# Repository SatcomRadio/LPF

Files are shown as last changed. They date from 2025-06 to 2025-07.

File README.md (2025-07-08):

# Low pass filter board

This repo consists of a board for making a low pass filter (LPF). 

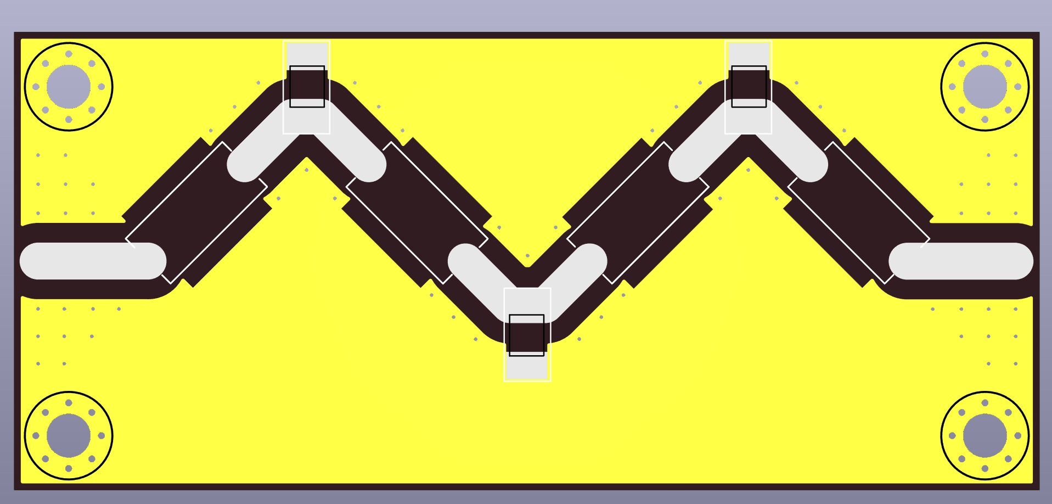
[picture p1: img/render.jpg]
render


You can use it with your own coils and RF capacitors for your desired frequency.

You can use a metal box like [this one](https://www.aliexpress.com/item/1005001849603652.html) of size 92x38x31mm to store it.

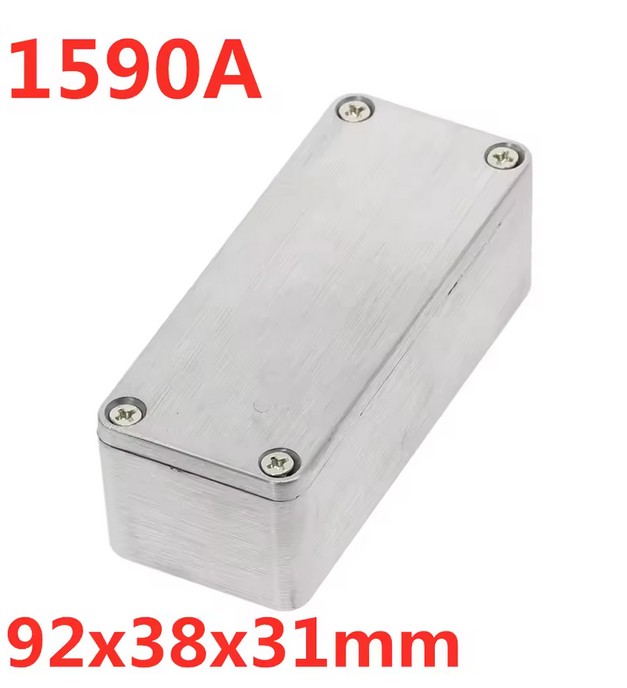
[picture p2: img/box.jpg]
box


------------------------

In order to make it work on satcom frequencies you will need:

```
3x 11pF RF capacitors (https://aliexpress.com/item/1005006664008969.html)
0.8mm enameled copper wire

Optional: Storage box (https://www.aliexpress.com/item/1005001849603652.html)
```

Schema:

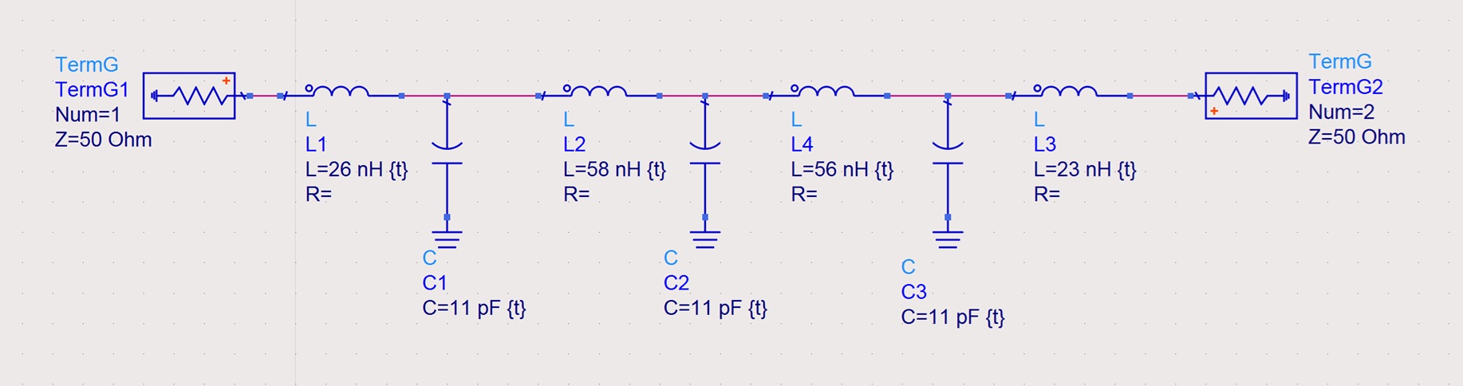
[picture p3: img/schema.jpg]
schema


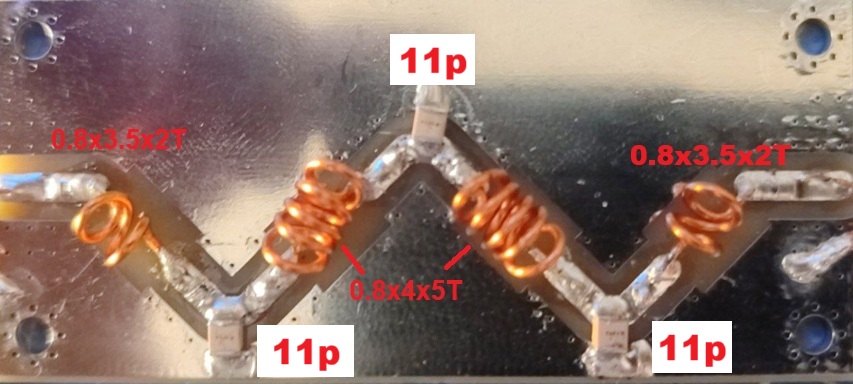
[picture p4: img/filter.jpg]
filter


Side coils instructions:  

```
0.8mm enameled wire, 3.5mm diameter, 2 turns spreaded
```

Middle coils instructions:  

```
0.8mm enameled wire, 4mm diameter, 5 turns spreaded
```

After adjusting with the nanovna you should be able to get this graph:

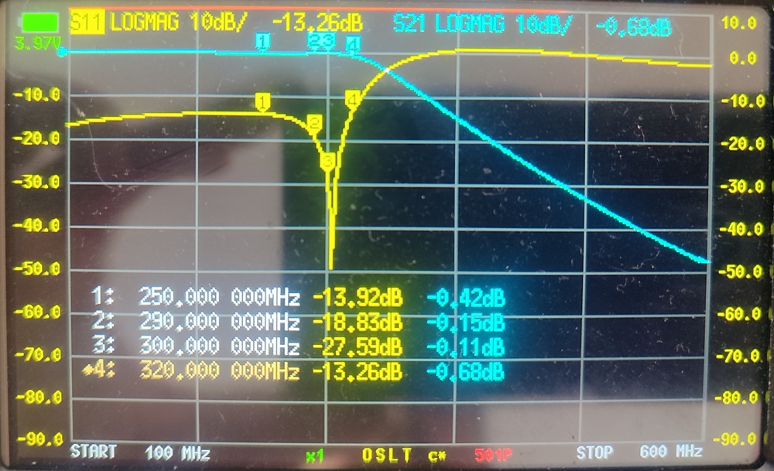
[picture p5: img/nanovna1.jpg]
nanovna


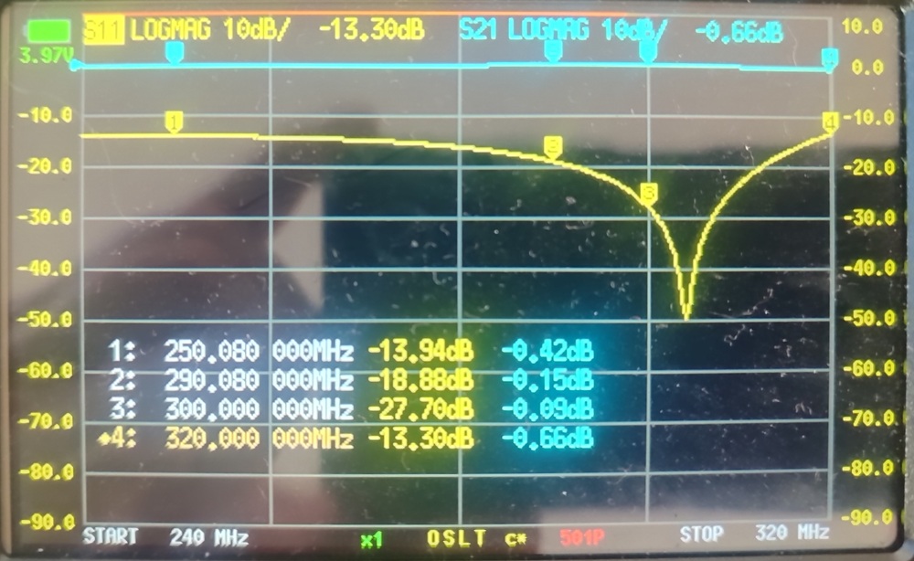
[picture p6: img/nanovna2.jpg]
nanovna


------------------------

## Ordering the PCB:

Download the Gerber file from this repo and order it a jlcpcb with the default options.  
The only option I've changed is to remove the manufacture code mark

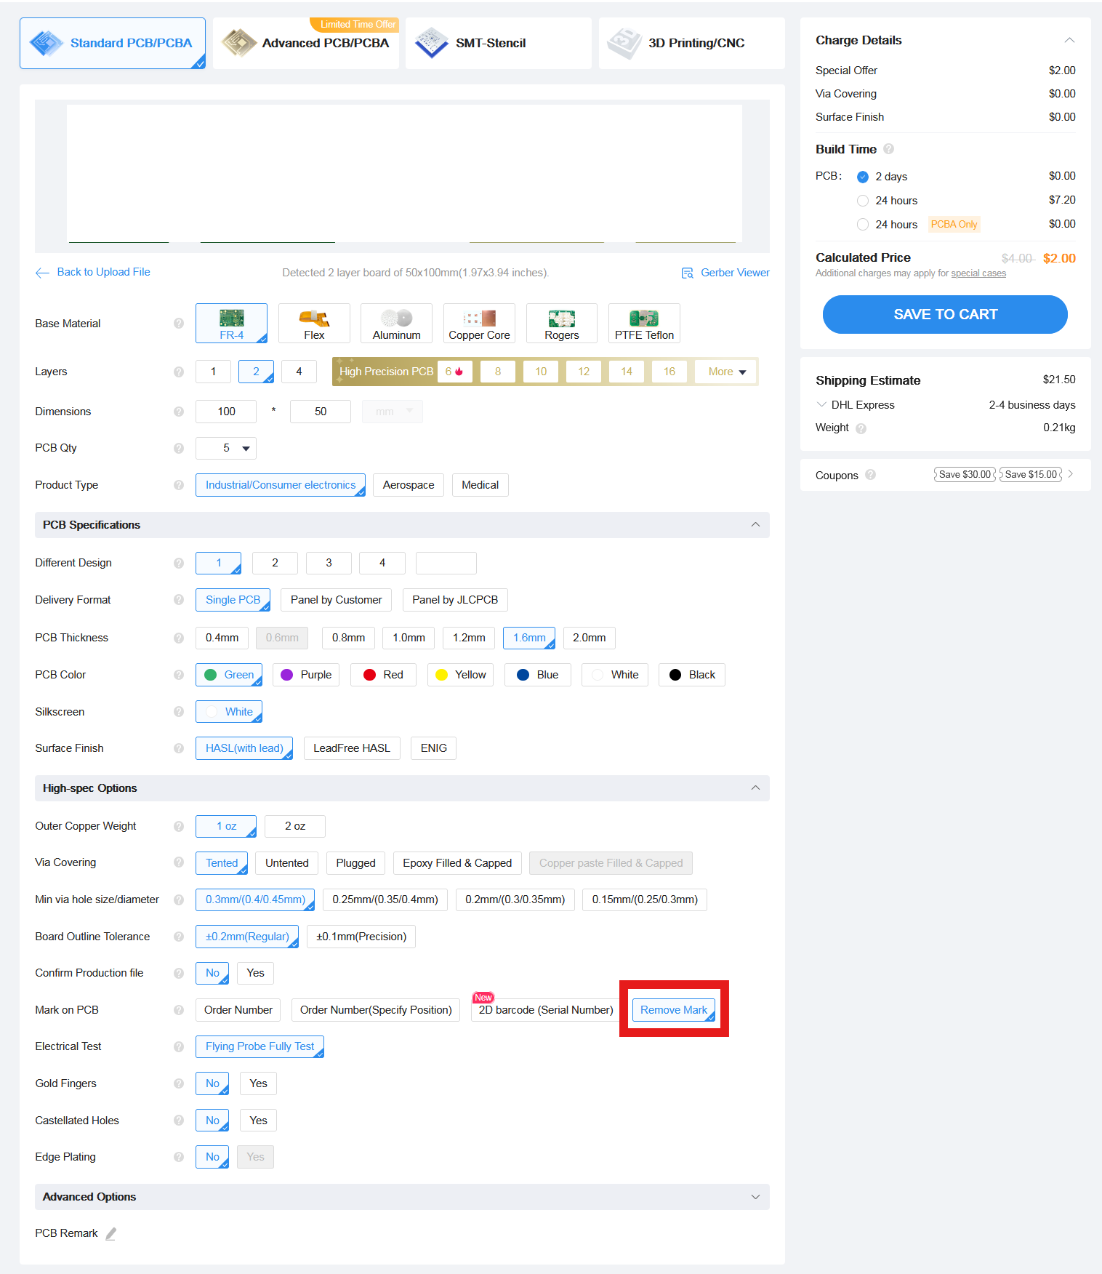
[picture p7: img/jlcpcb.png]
jlcpcb


#### Please make sure to visit the [satcom radio website](https://satcomradio.github.io/) for more information

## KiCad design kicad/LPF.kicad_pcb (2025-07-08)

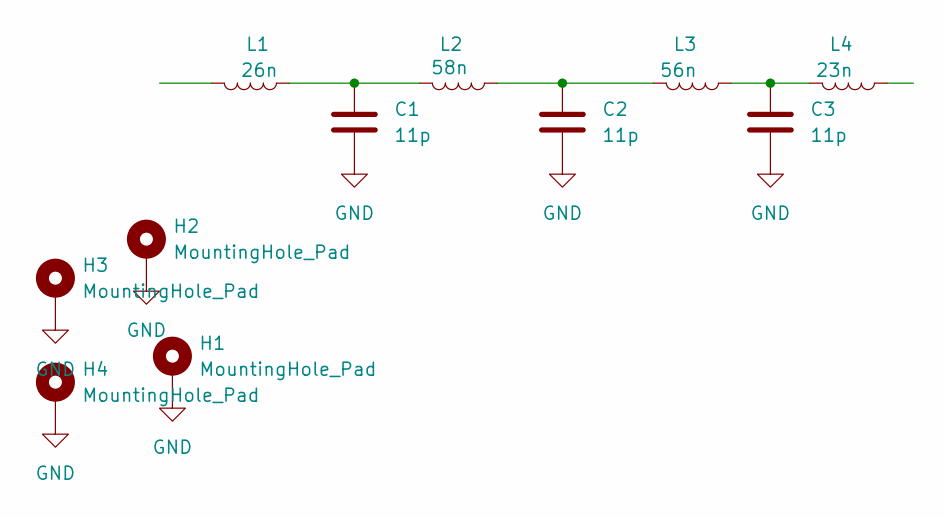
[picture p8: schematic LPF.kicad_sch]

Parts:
C1, C2, C3: 11p; RFCap_S
H1, H2, H3, H4: MountingHole_Pad; MountingHole_3.2mm_M3_Pad_Via
L1: 26n; Wound_Inductor_S
L2: 58n; Wound_Inductor_S
L3: 56n; Wound_Inductor_S
L4: 23n; Wound_Inductor_S

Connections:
GND: C1.2, C2.2, C3.2, H1.1, H2.1, H3.1, H4.1
unnamed: C1.1, L1.1, L2.1
unnamed: C2.1, L2.2, L3.1
unnamed: C3.1, L3.2, L4.1

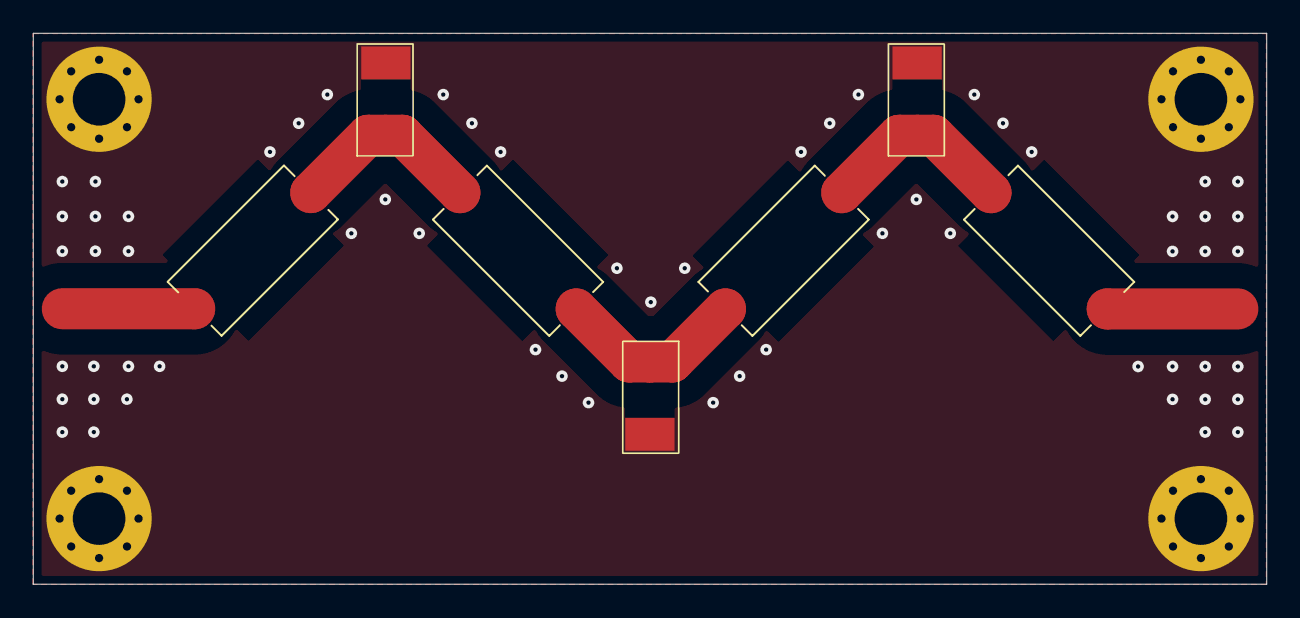
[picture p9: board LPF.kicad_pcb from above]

Board: 2 copper layers, 75.0 x 33.5 mm, 11 parts (0 on the bottom side), 4 nets.

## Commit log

2025-06-26 File commit
    [LPF.kicad_pcb, LPF.kicad_sch]
2025-07-08 Use 11pF instead of 12pF
    [LPF.kicad_pcb, LPF.kicad_sch]
